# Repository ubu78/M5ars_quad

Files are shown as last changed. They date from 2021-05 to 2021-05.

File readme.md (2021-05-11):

This git is for my M5Stack Version of the S.M.A.R.S. Quad.
smarsquadbaseheader

M5.A.R.S QUAD is a version of the S.M.A.R.S QUAD by Kevin Thomas whos project can be found here:
https://www.thingiverse.com/thing:2755973

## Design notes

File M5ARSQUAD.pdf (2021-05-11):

M5.A.R.S QUAD.

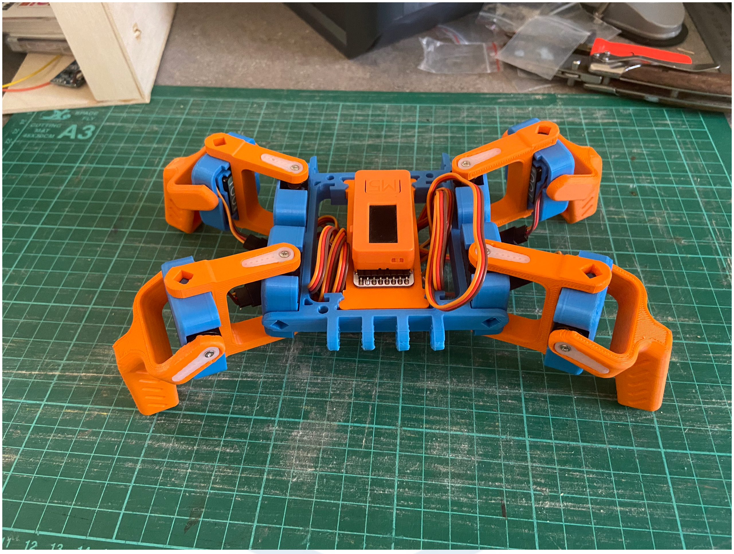
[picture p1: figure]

Introduction.

S.M.A.R.S stand for Screw-less Modular Assemble-able Robotic System and was originally created by Kevin Thomas from Switzerland and made available on thingiverse.
The S.M.A.R.S platform has gone through many revisions and conversions with the S.M.A.R.S Quad being the version that this guide is based on.

https://www.thingiverse.com/thing:2755973

In this guide I will show you how to build the S.M.A.R.S QUAD based robot using M5Stack 180 Servo pack, M5StickC controller and Servos Hat in order to bring the chassis to life.
This guide is broken into several steps which I hope make the assembly clear enough to follow.
Step 1 - Print the Parts.

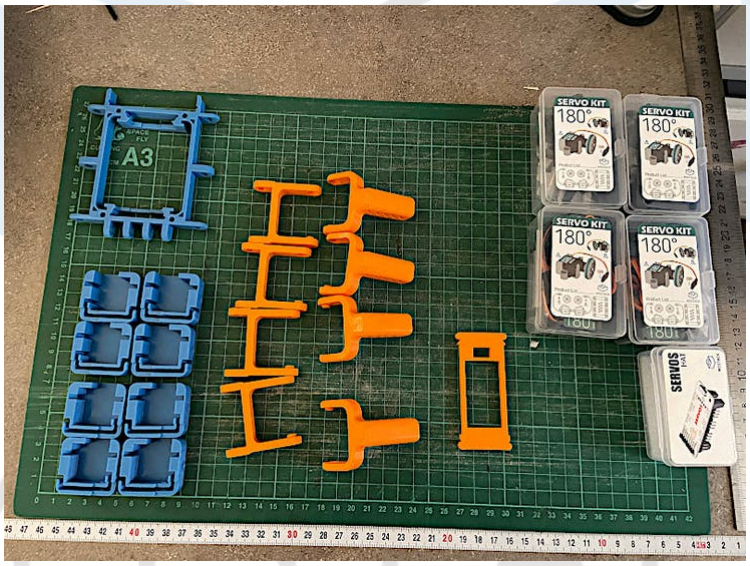
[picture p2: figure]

The 3D Printed Parts and Electronic Parts (minus M5StickC)

Go to https://www.thingiverse.com/thing:2755973 and download the S.M.A.R.S QUAD parts.

Print out 4 for the servo covers, 4 of the servo cover M's, 2 feet and 2 feet M's and the frame2.0. Next goto https://github.com/Ajb2k3/M5ars_quad/tree/main/3D and download 8servomountv3.stl and print out.

Check your printers tolerances as the fit of the mount was very tight to the frame and has been designed to fit securely.

## Step 2 - Modify the Servo's

Modifying the servos to use in the S.M.A.R.S QUAD is not as scary as it sounds. The modification is none damaging, non permanent, and does not break the warranty.

The servos come fitted with a mounting cage which allows it to be fitted to the frame found it the kit. To use the on the S.M.A.R.S QUAD we need to remove this frame. To remove the frame I just gently pushed the clips that hold the servo on so that the servo just pops out without breaking the clips.

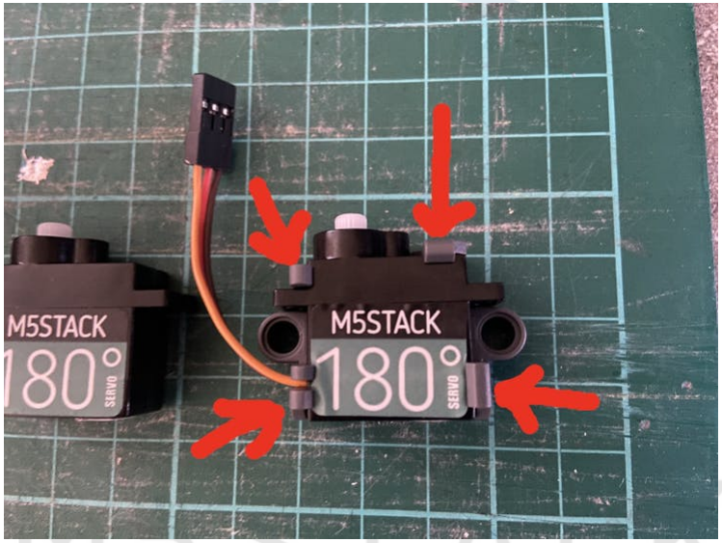
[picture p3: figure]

Push these clips outward gently to release servo. Start with the top two and then by gently twisting the servo, the bottom two will release. Do Not twist too much or you risk damaging the wire that are held between the left hand side clip.

## Step 3 - Fit servos to the S.M.A.R.S QUAD servo

mounts.

The M5Stack servos come with short leads and extensions. Place all the servos into the 8 mounts but don't press the cables in. Take 4 extension leads and connect them to 2 of the servos in the servo case and two to the servo M case, these will be the leg/knee servos.

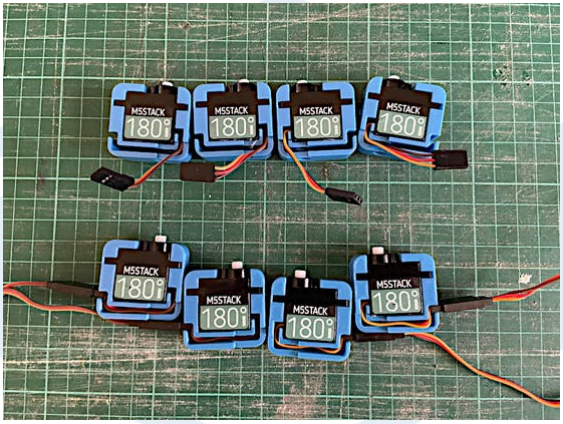
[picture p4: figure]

When done, tuck the cables with the extension leads into the covers so that they look like the above image. This is a tight fit with the extension leads but will fit with care.

Step 4 - Assemble the 3D Printed parts.

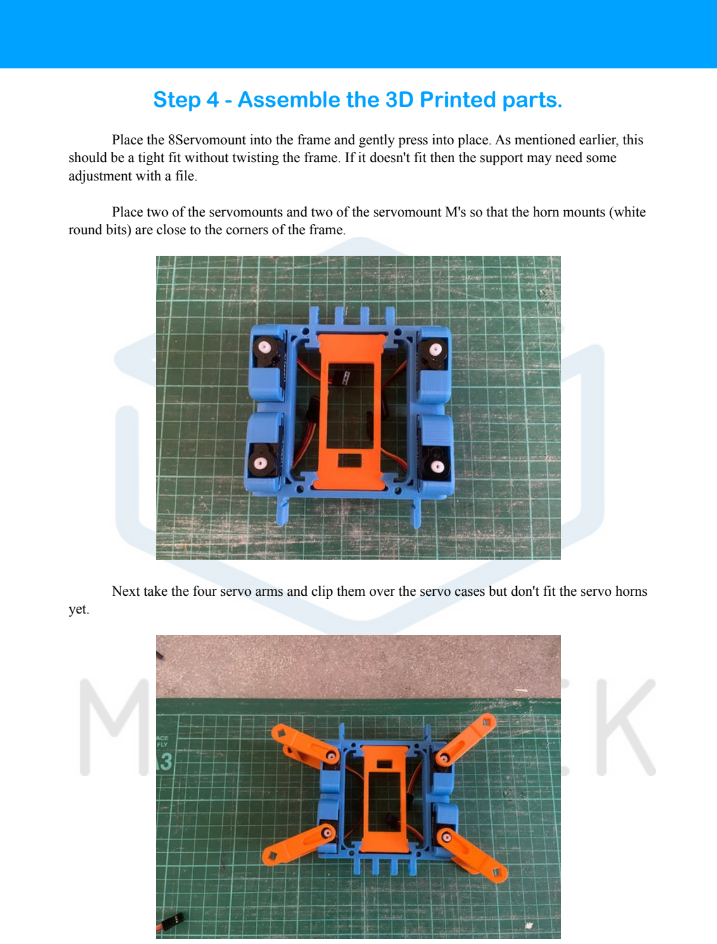
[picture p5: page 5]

Place the 8Servomount into the frame and gently press into place. As mentioned earlier, this should be a tight fit without twisting the frame. If it doesn't fit then the support may need some adjustment with a file.

Place two of the servomounts and two of the servomount M's so that the horn mounts (white round bits) are close to the corners of the frame.

Next take the four servo arms and clip them over the servo cases but don't fit the servo horns yet.

Step 5 - Connect the electronics.

The 8servo module should just fit into the support frame but the frame may need some filing if it doesn't. The switch points to the rear so that the RGB LED on the underside can shine through the hole of the support frame.

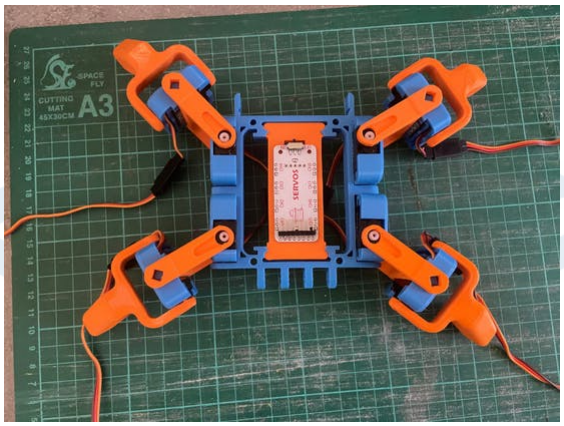
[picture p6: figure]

Next turn the assembly upside-down and connect the four "Hip" servos to the four outer servo ports marked CH1, CH4, CH5 and, CH8. These ports are used because the short leads mean that they wont reach any other port.

Next connect the four knee servo's making sure that the wire from each go to one of the corresponding available ports i.e.

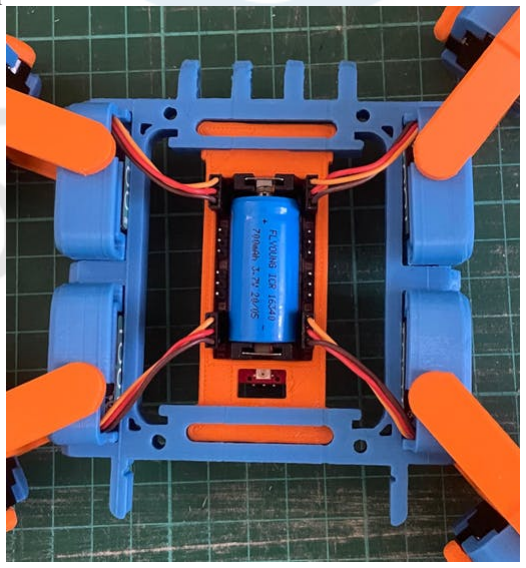
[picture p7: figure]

When connected the for servos should be connected as follows:

- Front Left Hip = CH4,
- Front Left Knee = CH3,
- Front Right Hip = CH8,
- Front Right Knee = CH7,
- Rear Left Hip = CH1,
- Rear Left Knee = CH2,
- Rear Right Hip = CH5,
- Rear Right Knee = CH6,

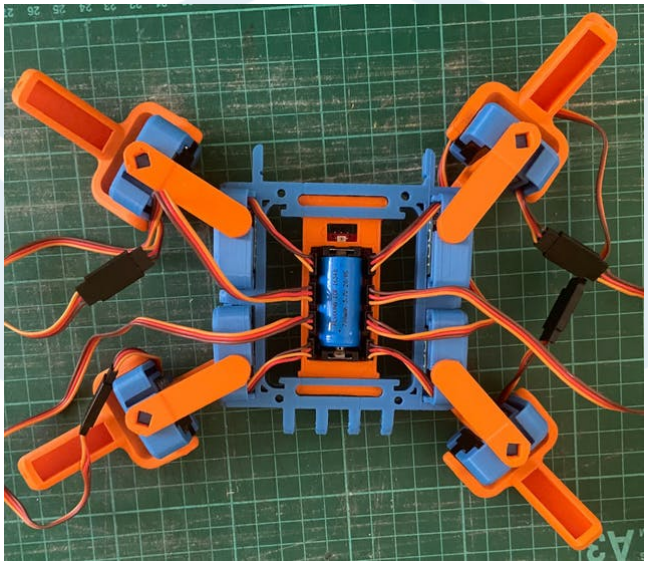
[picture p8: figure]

Finished Assembly

Now that the M5.A.R.S QUAD is complete, the next step is testing calibration and programming.

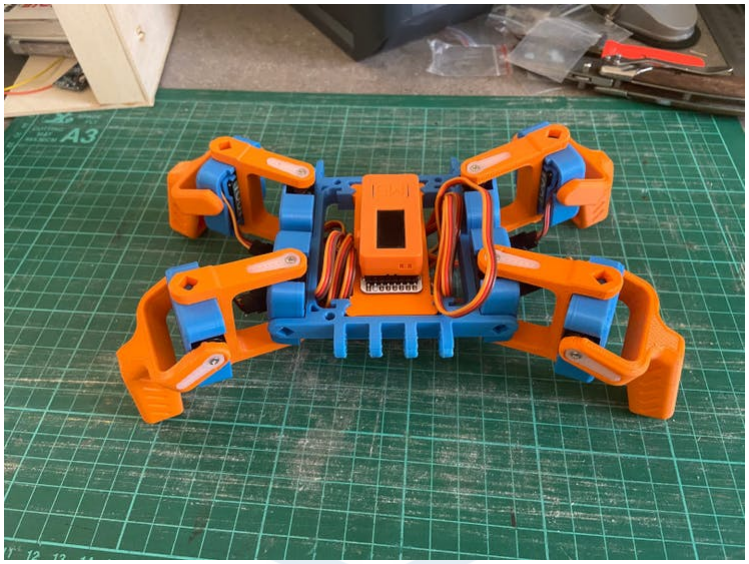
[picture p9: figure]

Further reading.
For good information and guides for non M5Stack based S.M.A.R.S projects you can check out https://www.smarsfan.com by Kevin McAleer.

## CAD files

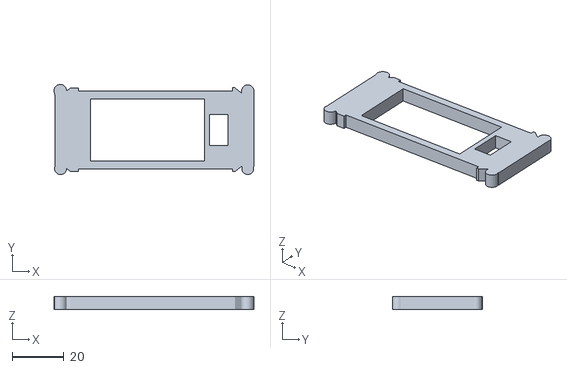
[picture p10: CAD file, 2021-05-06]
3D/8servomount v3.stl
77.1 x 34.8 x 5.00
